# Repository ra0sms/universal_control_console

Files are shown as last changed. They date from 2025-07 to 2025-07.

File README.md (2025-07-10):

## Universal Control Console (UCC)

The device can control any type of antenna switches. It has 8 independent programmable outputs and also can control [my version of receiving antenna K9AY](https://github.com/ra0sms/K9AY_with_wifi).

More information (in Russian, but Translate button still works) - https://ra0sms.com/ucc/

### [Schematic](KiCad/wired_console_k9ay/wired_console_k9ay.pdf)

### Outputs description

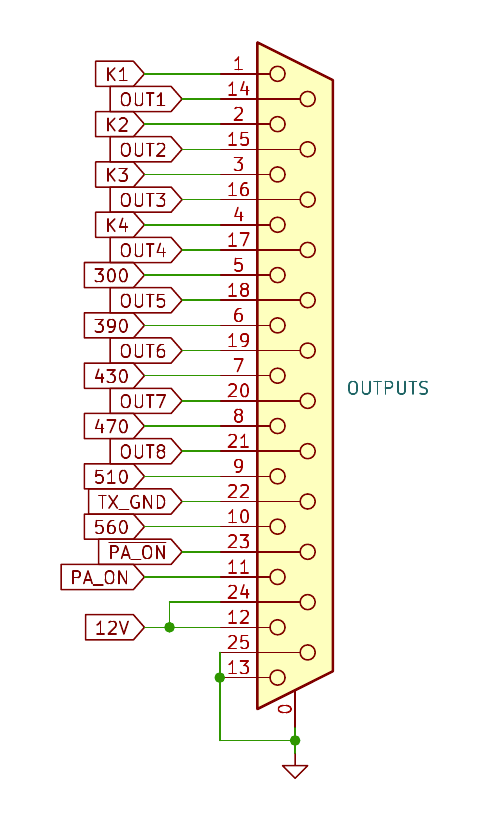
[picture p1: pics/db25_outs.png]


| DB25 pins | Description |
| --- | --- |
| 1 | **K1** - open collector out for K9AY direction control |
| 2 | **K2** - open collector out for K9AY direction control |
| 3 | **K3** - open collector out for K9AY direction control |
| 4 | **K4** - open collector out for K9AY direction control |
| 5 | **300** - open collector out for K9AY load control |
| 6 | **390** - open collector out for K9AY load control |
| 7 | **430** - open collector out for K9AY load control |
| 8 | **470** - open collector out for K9AY load control |
| 9 | **510** - open collector out for K9AY load control |
| 10 | **560** - open collector out for K9AY load control |
| 11 | **PA_ON** - open collector out for K9AY preamplifier control |
| 12 | **12V** - output voltage (goes directly from power supply connector with the diode protection) |
| 13 | **GND** - Ground |
| 14 | **OUT1** - First programmable output (when activated, has 12V out with fuse protection) |
| 15 | **OUT2** - Second programmable output (when activated, has 12V out with fuse protection) |
| 16 | **OUT3** - Third programmable output (when activated, has 12V out with fuse protection) |
| 17 | **OUT4** - Fourth programmable output (when activated, has 12V out with fuse protection) |
| 18 | **OUT5** - Fifth programmable output (when activated, has 12V out with fuse protection) |
| 19 | **OUT6** - Sixth programmable output (when activated, has 12V out with fuse protection) |
| 20 | **OUT7** - Seventh programmable output (when activated, has 12V out with fuse protection) |
| 21 | **OUT8** - Eighth programmable output (when activated, has 12V out with fuse protection) |
| 22 | **TX_GND** - when PTT activated, has connection to ground |
| 23 | **$\overline{\text{PAON}}$** - when Preamp button pressed, has 12V out without any protection |
| 24 | **12V** - output voltage (goes directly from power supply connector with the diode protection) |
| 25 | **GND** - Ground |

### Some photos

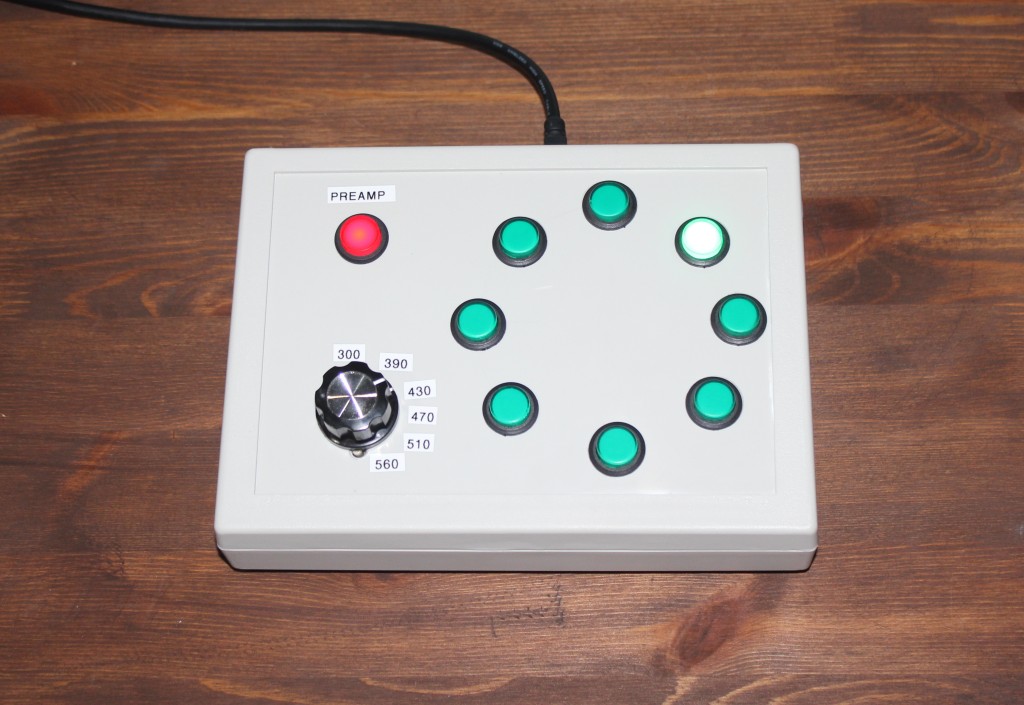
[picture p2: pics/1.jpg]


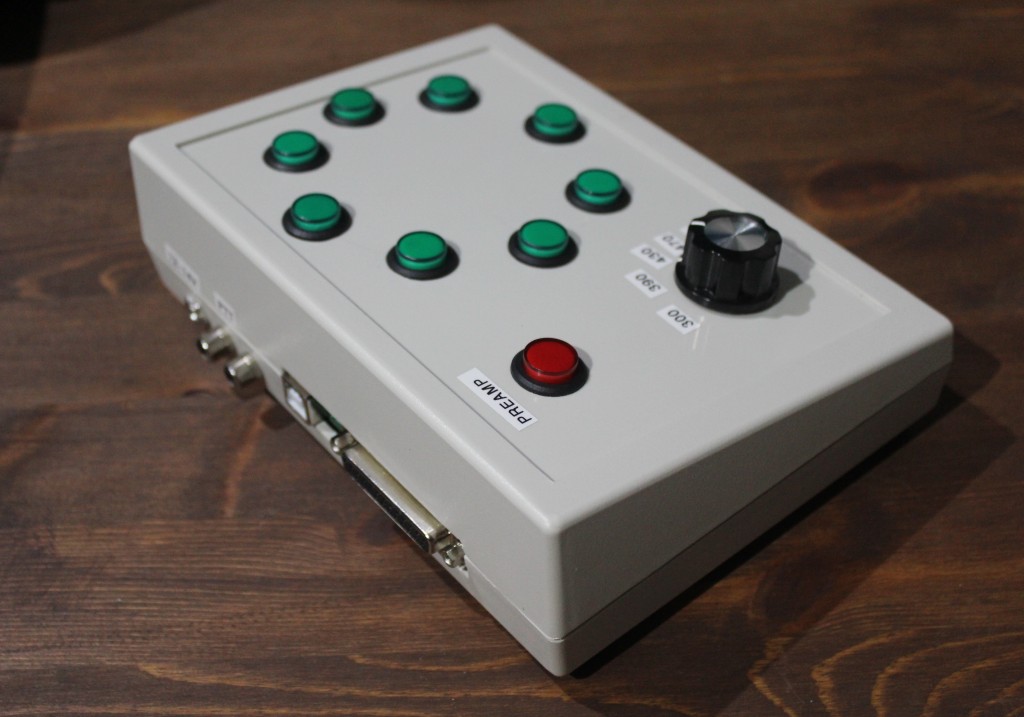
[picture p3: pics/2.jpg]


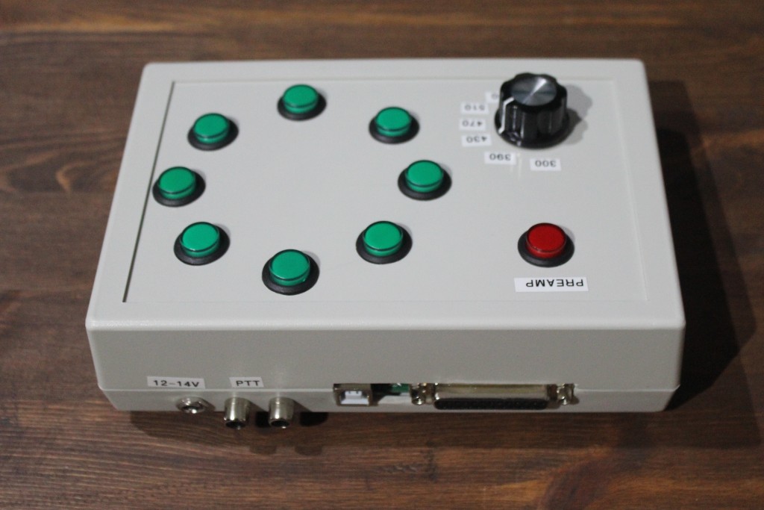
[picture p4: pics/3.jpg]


### GUI software for setting up outputs

You can choose outputs which will be activated when you push the buttons. Just connect USB to PC, choose com port and click Connect button.

[EXE-file (Windows OS)](gui/gui.zip)

[Python Script (Linux OS)](gui/gui.py)

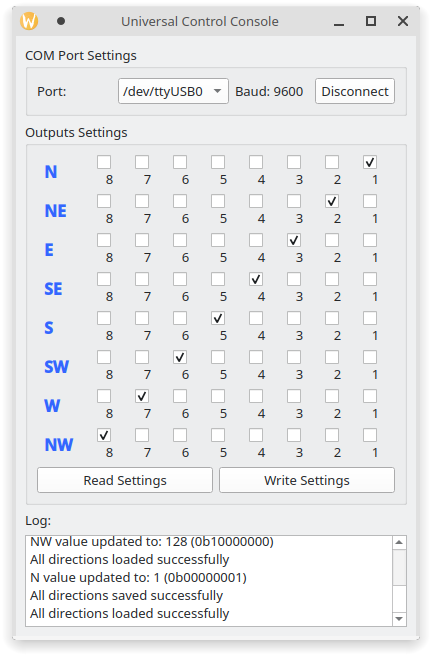
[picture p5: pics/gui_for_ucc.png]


### Antenna rotators emulator

UCC also can work with hamradio software, which use Yaesu rotator protocol. UCC can emulate a rotation at a given angle. You can use it with any supported software. For example [PST Rotator AZ](https://www.pstrotator.com/) and [DXLog](https://dxlog.net/).

### [Video with example or working](https://youtu.be/TXcX0s2ozSk)

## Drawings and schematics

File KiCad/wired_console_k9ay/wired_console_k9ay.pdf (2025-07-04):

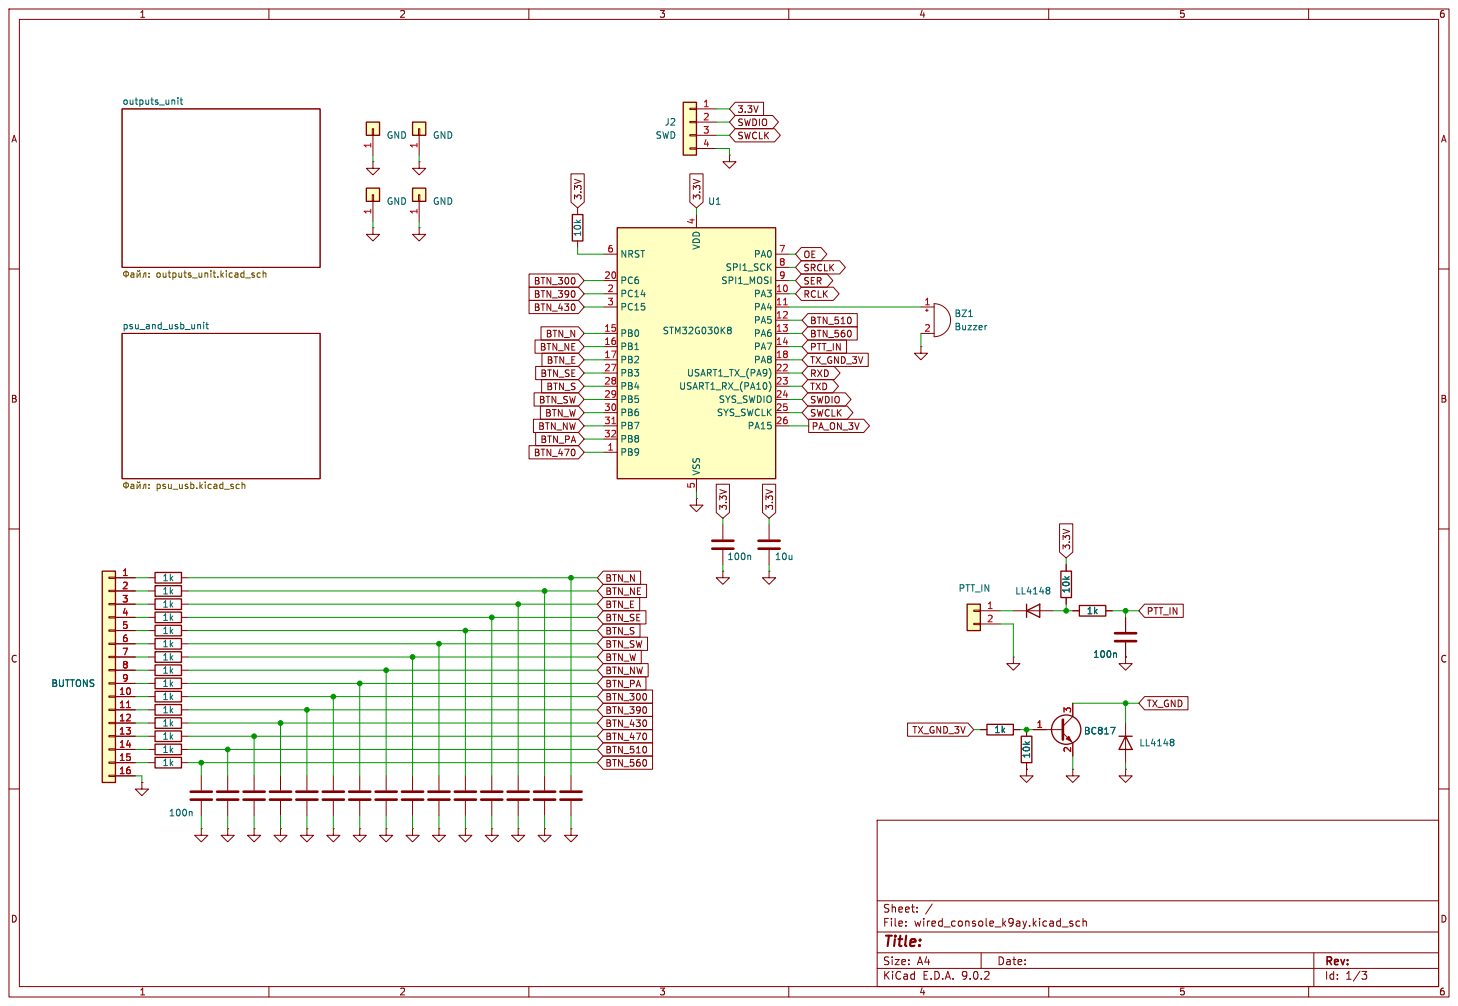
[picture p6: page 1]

Id: 1/3 Title: File: wired_console_k9ay.kicad_sch Sheet: /

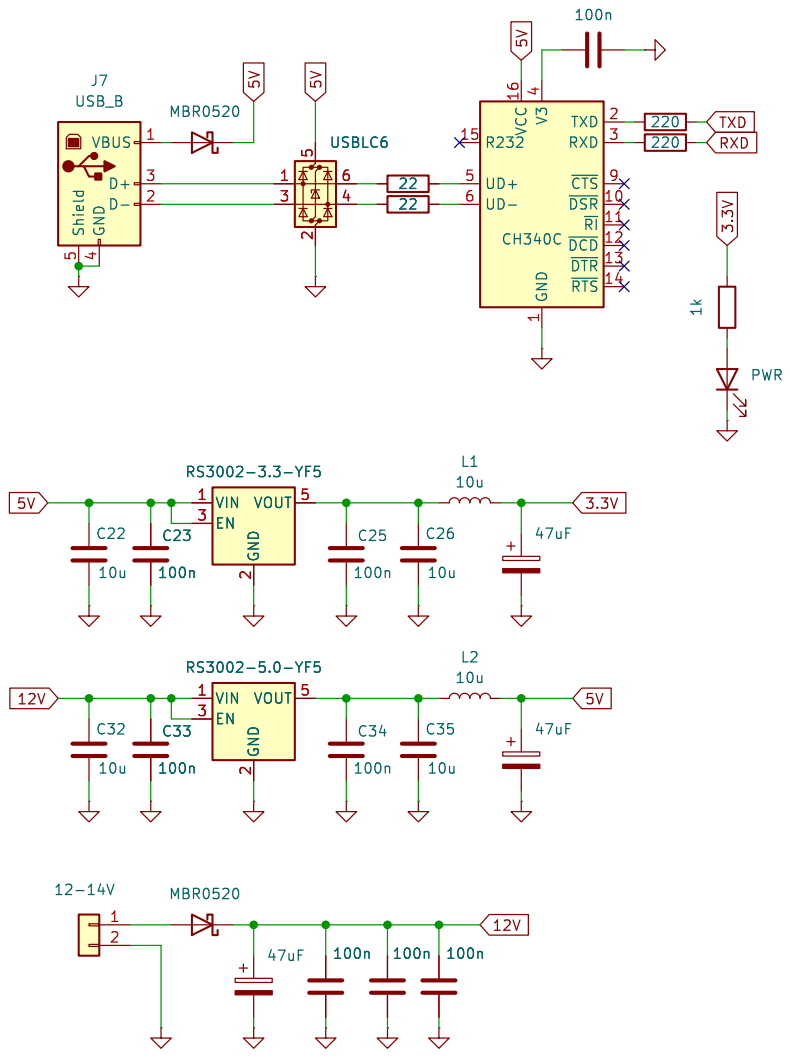
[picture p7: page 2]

Id: 2/3 Title: File: psu_usb.kicad_sch Sheet: /psu_and_usb_unit/ 12

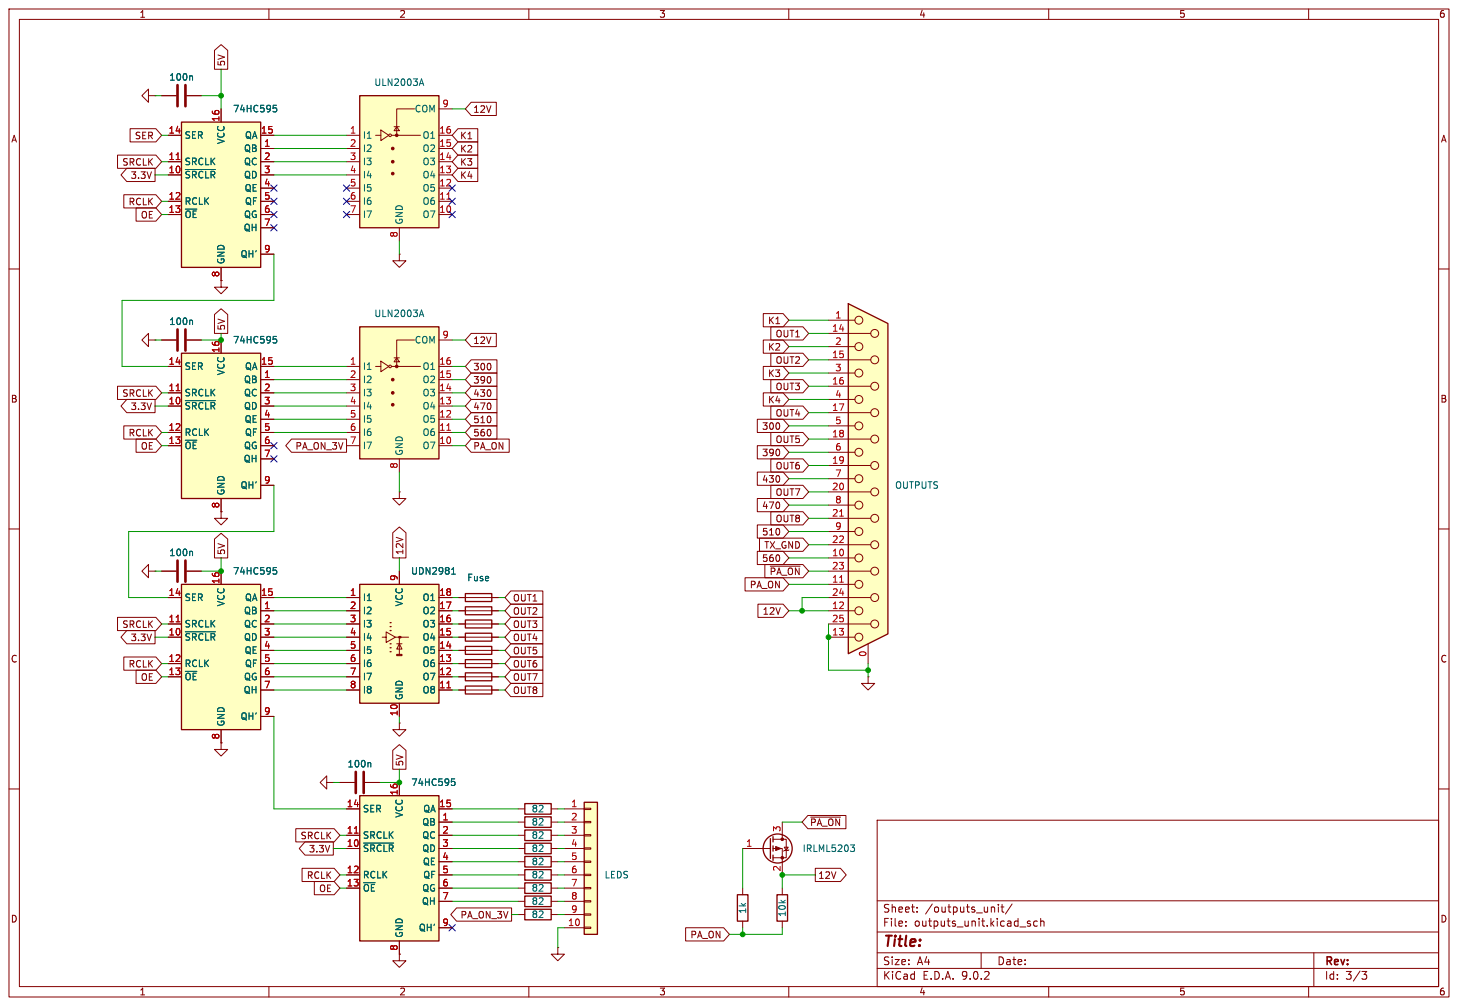
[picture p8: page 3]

Id: 3/3 Title: File: outputs_unit.kicad_sch Sheet: /outputs_unit/

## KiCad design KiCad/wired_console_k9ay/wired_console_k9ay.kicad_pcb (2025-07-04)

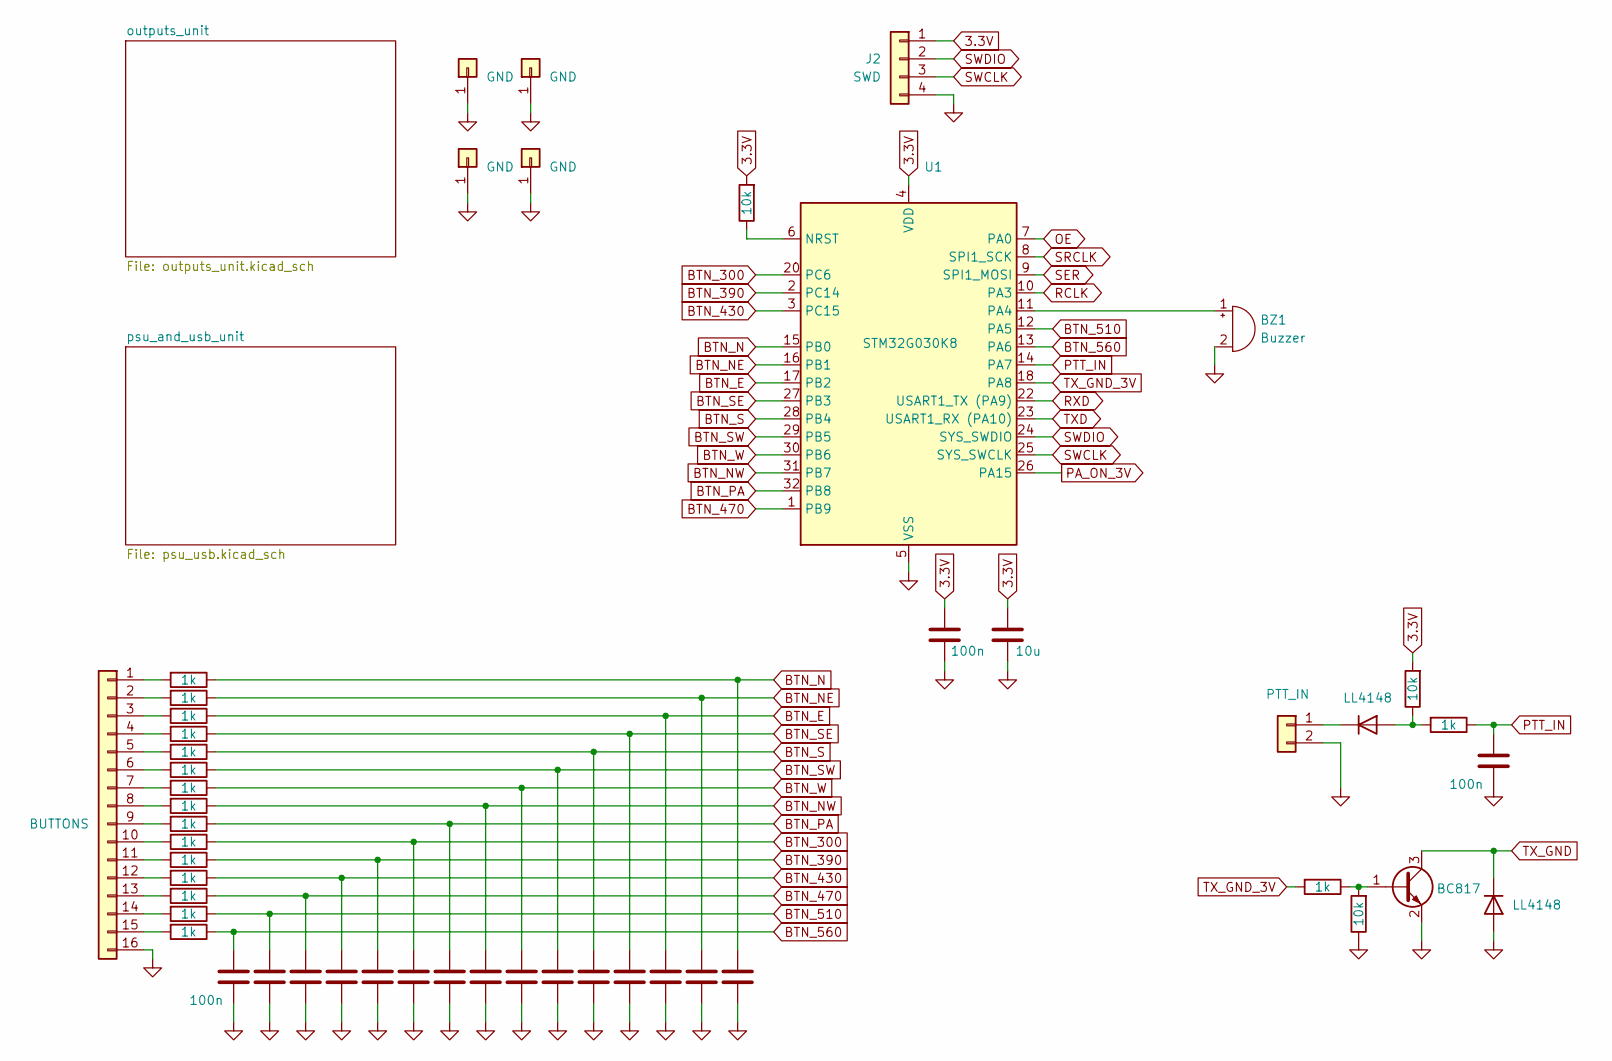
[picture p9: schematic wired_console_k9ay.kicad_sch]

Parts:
BZ1: Buzzer; Buzzer_12x9.5RM7.6
C1, C2, C3, C4, C5, C6, C7, C8, C9, C10, C11, C12, C13, C14, C15, C16, C37: 100n; C_1206_3216Metric_Pad1.33x1.80mm_HandSolder
C17: 10u; C_1206_3216Metric_Pad1.33x1.80mm_HandSolder
D3, D5: LL4148; D_MiniMELF
J1: BUTTONS; PinHeader_1x16_P2.54mm_Vertical
J2: SWD; PinSocket_1x04_P2.54mm_Vertical
J3: PTT_IN; PinHeader_1x02_P2.54mm_Vertical
J8, J9, J10, J11: GND; SolderWire-6sqmm_1x01_D3.5mm_OD7mm
Q2: BC817; SOT-23
R1, R2, R3, R4, R5, R6, R7, R8, R9, R10, R11, R12, R13, R14, R15, R34, R36: 1k; R_1206_3216Metric
R16, R33, R35: 10k; R_1206_3216Metric
U1: STM32G030K8; LQFP-32_7x7mm_P0.8mm

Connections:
3.3V: C16.1, C17.1, J2.1, R16.2, R33.2, U1.4 (VDD); also elsewhere on the board
BTN_300: C6.1, R10.1, U1.20 (PC6)
BTN_390: C5.1, R11.1, U1.2 (PC14)
BTN_430: C4.1, R12.1, U1.3 (PC15)
BTN_470: C3.1, R13.1, U1.1 (PB9)
BTN_510: C2.1, R14.1, U1.12 (PA5)
BTN_560: C1.1, R15.1, U1.13 (PA6)
BTN_E: C13.1, R3.1, U1.17 (PB2)
BTN_N: C15.1, R1.1, U1.15 (PB0)
BTN_NE: C14.1, R2.1, U1.16 (PB1)
BTN_NW: C8.1, R8.1, U1.31 (PB7)
BTN_PA: C7.1, R9.1, U1.32 (PB8)
BTN_S: C11.1, R5.1, U1.28 (PB4)
BTN_SE: C12.1, R4.1, U1.27 (PB3)
BTN_SW: C10.1, R6.1, U1.29 (PB5)
BTN_W: C9.1, R7.1, U1.30 (PB6)
GND: BZ1.2 (-), C1.2, C2.2, C3.2, C4.2, C5.2, C6.2, C7.2, C8.2, C9.2, C10.2, C11.2, C12.2, C13.2, C14.2, C15.2, C16.2, C17.2, C37.2, D5.2 (A), J1.16, J2.4, J3.2, J8.1, J9.1, J10.1, J11.1, Q2.2 (E), R35.1, U1.5 (VSS); also elsewhere on the board
unnamed: BZ1.1 (+), U1.11 (PA4)
unnamed: D3.2 (A), R33.1, R34.2
unnamed: D3.1 (K), J3.1
unnamed: J1.1, R1.2
unnamed: J1.2, R2.2
unnamed: J1.3, R3.2
unnamed: J1.4, R4.2
unnamed: J1.5, R5.2
unnamed: J1.6, R6.2
unnamed: J1.7, R7.2
unnamed: J1.8, R8.2
unnamed: J1.9, R9.2
unnamed: J1.10, R10.2
unnamed: J1.11, R11.2
unnamed: J1.12, R12.2
unnamed: J1.13, R13.2
unnamed: J1.14, R14.2
unnamed: J1.15, R15.2
unnamed: Q2.1 (B), R35.2, R36.1
unnamed: R16.1, U1.6 (NRST)
OE: U1.7 (PA0); also elsewhere on the board
PA_ON_3V: U1.26 (PA15); also elsewhere on the board
PTT_IN: C37.1, R34.1, U1.14 (PA7)
RCLK: U1.10 (PA3); also elsewhere on the board
RXD: U1.22 (USART1_TX (PA9)); also elsewhere on the board
SER: U1.9 (SPI1_MOSI); also elsewhere on the board
SRCLK: U1.8 (SPI1_SCK); also elsewhere on the board
SWCLK: J2.3, U1.25 (SYS_SWCLK)
SWDIO: J2.2, U1.24 (SYS_SWDIO)
TXD: U1.23 (USART1_RX (PA10)); also elsewhere on the board
TX_GND: D5.1 (K), Q2.3 (C); also elsewhere on the board
TX_GND_3V: R36.2, U1.18 (PA8)

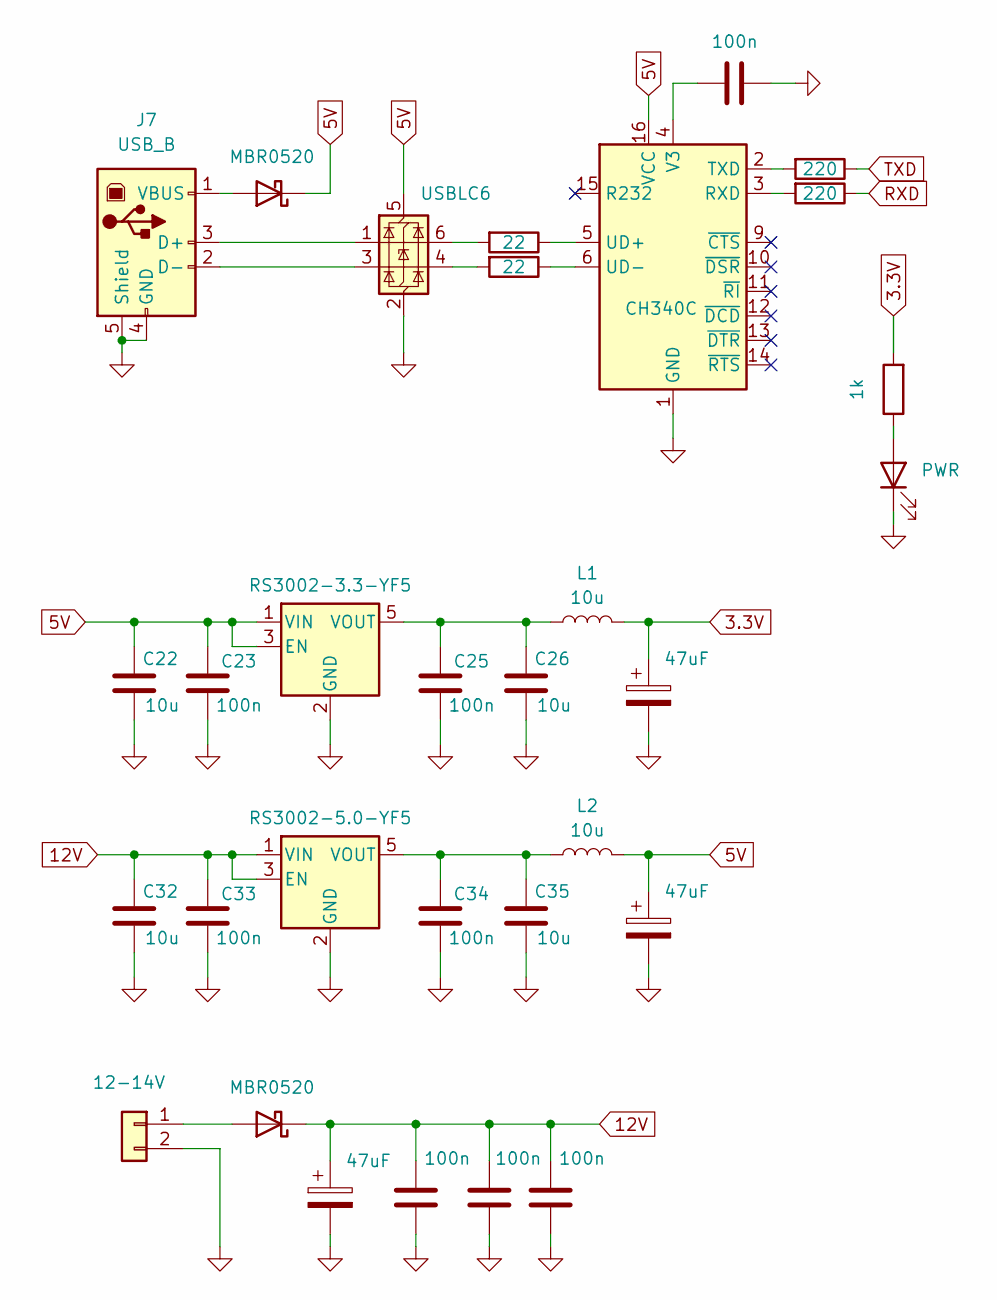
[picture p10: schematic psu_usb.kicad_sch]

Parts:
C18, C27, C36: 47uF; CP_Radial_D5.0mm_P2.50mm
C19, C20, C21, C24: 100n; C_1206_3216Metric
C22, C26, C32, C35: 10u; C_1206_3216Metric_Pad1.33x1.80mm_HandSolder
C23, C25, C33, C34: 100n; C_1206_3216Metric_Pad1.33x1.80mm_HandSolder
D1, D2: MBR0520; D_SOD-123
D4: PWR; LED_1206_3216Metric
J4: 12-14V; PinHeader_1x02_P2.54mm_Vertical
J7: USB_B; USB_B_Lumberg_2411_02_Horizontal
L1, L2: 10u; L_1206_3216Metric
R17, R18: 22; R_1206_3216Metric
R19, R20: 220; R_1206_3216Metric
R21: 1k; R_1206_3216Metric
U2: USBLC6; SOT-23-6
U3: CH340C; SOIC-16_3.9x9.9mm_P1.27mm
U4: RS3002-3.3-YF5; SOT-23-5
U12: RS3002-5.0-YF5; SOT-23-5

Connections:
3.3V: C27.1, L1.2, R21.2; also elsewhere on the board
5V: C22.1, C23.1, C36.1, D2.1 (K), L2.2, U2.5 (VBUS), U3.16 (VCC), U4.1 (VIN), U4.3 (EN); also elsewhere on the board
12V: C18.1, C19.1, C20.1, C21.1, C32.1, C33.1, D1.1 (K), U12.1 (VIN), U12.3 (EN); also elsewhere on the board
GND: C18.2, C19.2, C20.2, C21.2, C22.2, C23.2, C24.2, C25.2, C26.2, C27.2, C32.2, C33.2, C34.2, C35.2, C36.2, D4.1 (K), J4.2, J7.4 (GND), J7.5 (Shield), U2.2 (GND), U3.1 (GND), U4.2 (GND), U12.2 (GND); also elsewhere on the board
unnamed: D1.2 (A), J4.1
unnamed: D2.2 (A), J7.1 (VBUS)
unnamed: D4.2 (A), R21.1
unnamed: J7.3 (D+), U2.1 (I/O1)
unnamed: J7.2 (D-), U2.3 (I/O2)
unnamed: R17.2, U2.6 (I/O1)
unnamed: R18.2, U2.4 (I/O2)
unnamed: R20.2, U3.3 (RXD)
unnamed: R19.2, U3.2 (TXD)
unnamed: R17.1, U3.5 (UD+)
unnamed: R18.1, U3.6 (UD-)
unnamed: C24.1, U3.4 (V3)
unnamed: C25.1, C26.1, L1.1, U4.5 (VOUT)
unnamed: C34.1, C35.1, L2.1, U12.5 (VOUT)
RXD: R20.1; also elsewhere on the board
TXD: R19.1; also elsewhere on the board

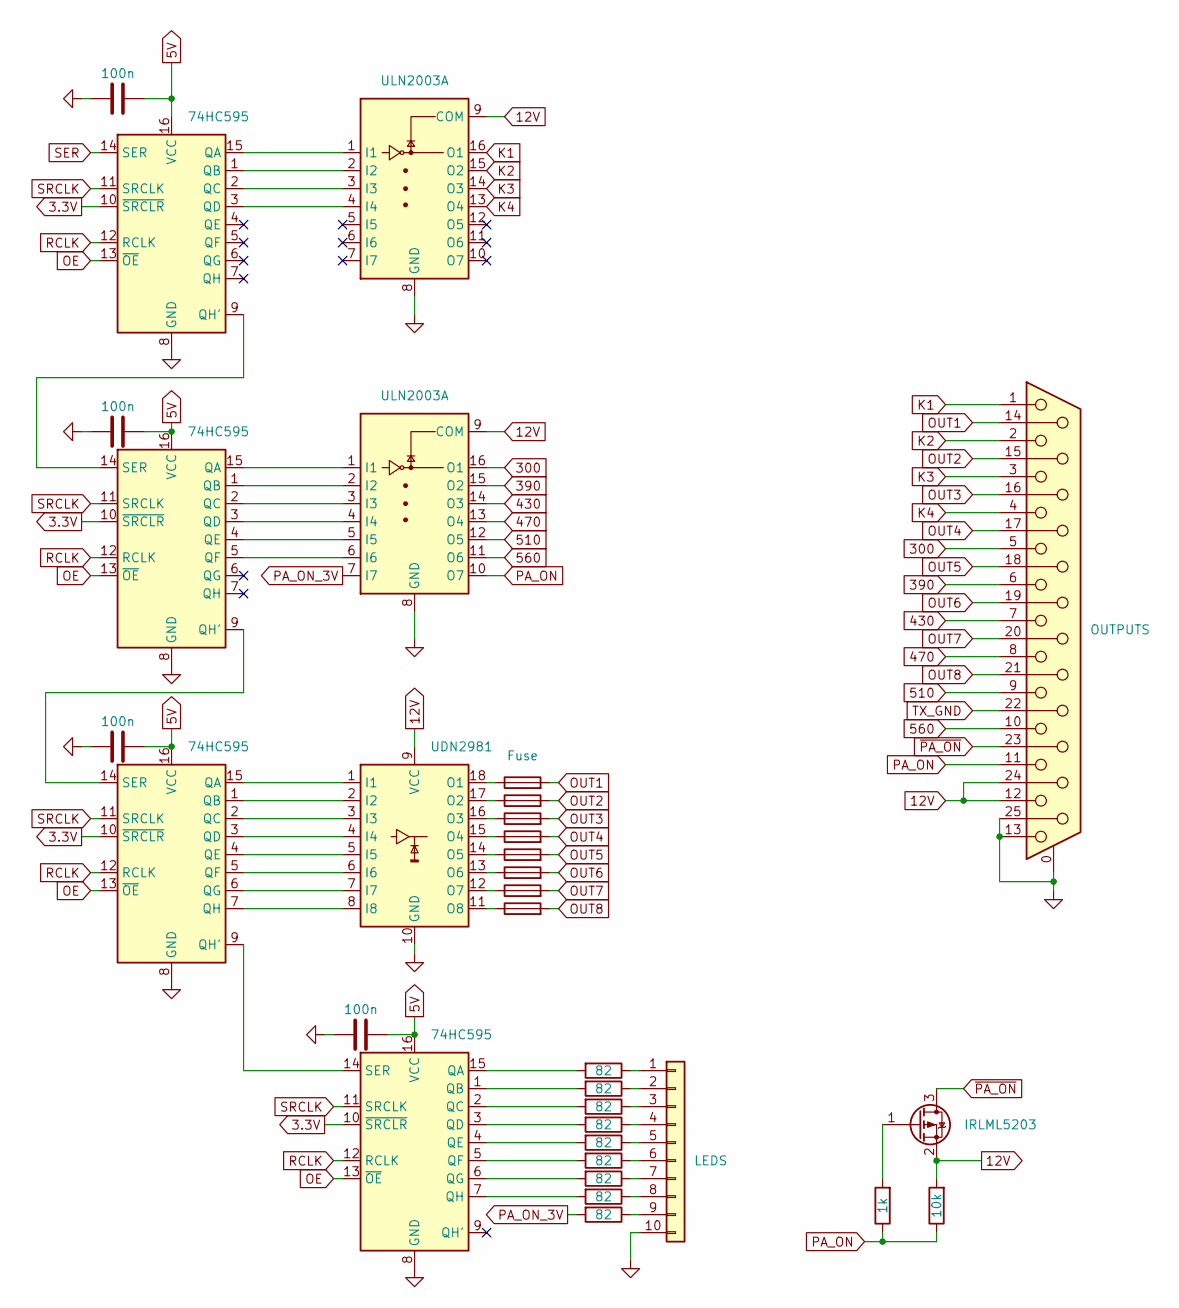
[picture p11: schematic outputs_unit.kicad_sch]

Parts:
C28, C29, C30, C31: 100n; C_1206_3216Metric
F1, F2, F3, F4, F5, F6, F7, F8: Fuse; R_1206_3216Metric
J5: LEDS; PinSocket_1x10_P2.54mm_Vertical
J6: OUTPUTS; DSUB-25_Socket_Horizontal_P2.77x2.84mm_EdgePinOffset4.94mm_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
Q1: IRLML5203; SOT-23
R22, R23, R24, R25, R26, R27, R28, R29, R30: 82; R_1206_3216Metric
R31: 1k; R_1206_3216Metric
R32: 10k; R_1206_3216Metric
U5, U6, U7, U11: 74HC595; SOIC-16_3.9x9.9mm_P1.27mm
U8, U9: ULN2003A; SOIC-16_3.9x9.9mm_P1.27mm
U10: UDN2981; DIP-18_W7.62mm_LongPads

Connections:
3.3V: U5.10 (~SRCLR), U6.10 (~SRCLR), U7.10 (~SRCLR), U11.10 (~SRCLR); also elsewhere on the board
5V: C28.2, C29.2, C30.2, C31.2, U5.16 (VCC), U6.16 (VCC), U7.16 (VCC), U11.16 (VCC); also elsewhere on the board
12V: J6.12, J6.24, Q1.2 (S), R32.2, U8.9 (COM), U9.9 (COM), U10.9 (VCC); also elsewhere on the board
300: J6.5, U9.16 (O1)
390: J6.6, U9.15 (O2)
430: J6.7, U9.14 (O3)
470: J6.8, U9.13 (O4)
510: J6.9, U9.12 (O5)
560: J6.10, U9.11 (O6)
GND: C28.1, C29.1, C30.1, C31.1, J5.10, J6.0 (PAD), J6.13, J6.25, U5.8 (GND), U6.8 (GND), U7.8 (GND), U8.8 (GND), U9.8 (GND), U10.10 (GND), U11.8 (GND); also elsewhere on the board
K1: J6.1, U8.16 (O1)
K2: J6.2, U8.15 (O2)
K3: J6.3, U8.14 (O3)
K4: J6.4, U8.13 (O4)
unnamed: J5.1, R22.1
unnamed: J5.2, R23.1
unnamed: J5.3, R24.1
unnamed: J5.4, R25.1
unnamed: J5.5, R26.1
unnamed: J5.6, R27.1
unnamed: J5.7, R28.1
unnamed: J5.8, R29.1
unnamed: J5.9, R30.1
unnamed: Q1.1 (G), R31.2
unnamed: U5.15 (QA), U8.1 (I1)
unnamed: U5.1 (QB), U8.2 (I2)
unnamed: U5.2 (QC), U8.3 (I3)
unnamed: U5.3 (QD), U8.4 (I4)
unnamed: U5.9 (QH'), U6.14 (SER)
unnamed: U6.15 (QA), U9.1 (I1)
unnamed: U6.1 (QB), U9.2 (I2)
unnamed: U6.2 (QC), U9.3 (I3)
unnamed: U6.3 (QD), U9.4 (I4)
unnamed: U6.4 (QE), U9.5 (I5)
unnamed: U6.5 (QF), U9.6 (I6)
unnamed: U6.9 (QH'), U7.14 (SER)
unnamed: U7.15 (QA), U10.1 (I1)
unnamed: U7.1 (QB), U10.2 (I2)
unnamed: U7.2 (QC), U10.3 (I3)
unnamed: U7.3 (QD), U10.4 (I4)
unnamed: U7.4 (QE), U10.5 (I5)
unnamed: U7.5 (QF), U10.6 (I6)
unnamed: U7.6 (QG), U10.7 (I7)
unnamed: U7.7 (QH), U10.8 (I8)
unnamed: F1.1, U10.18 (O1)
unnamed: F2.1, U10.17 (O2)
unnamed: F3.1, U10.16 (O3)
unnamed: F4.1, U10.15 (O4)
unnamed: F5.1, U10.14 (O5)
unnamed: F6.1, U10.13 (O6)
unnamed: F7.1, U10.12 (O7)
unnamed: F8.1, U10.11 (O8)
unnamed: R22.2, U11.15 (QA)
unnamed: R23.2, U11.1 (QB)
unnamed: R24.2, U11.2 (QC)
unnamed: R25.2, U11.3 (QD)
unnamed: R26.2, U11.4 (QE)
unnamed: R27.2, U11.5 (QF)
unnamed: R28.2, U11.6 (QG)
unnamed: R29.2, U11.7 (QH)
unnamed: U7.9 (QH'), U11.14 (SER)
OE: U5.13 (~OE), U6.13 (~OE), U7.13 (~OE), U11.13 (~OE); also elsewhere on the board
OUT1: F1.2, J6.14
OUT2: F2.2, J6.15
OUT3: F3.2, J6.16
OUT4: F4.2, J6.17
OUT5: F5.2, J6.18
OUT6: F6.2, J6.19
OUT7: F7.2, J6.20
OUT8: F8.2, J6.21
PA_ON: J6.11, R31.1, R32.1, U9.10 (O7)
PA_ON_3V: R30.2, U9.7 (I7); also elsewhere on the board
RCLK: U5.12 (RCLK), U6.12 (RCLK), U7.12 (RCLK), U11.12 (RCLK); also elsewhere on the board
SER: U5.14 (SER); also elsewhere on the board
SRCLK: U5.11 (SRCLK), U6.11 (SRCLK), U7.11 (SRCLK), U11.11 (SRCLK); also elsewhere on the board
TX_GND: J6.22; also elsewhere on the board
~PA_ON: J6.23, Q1.3 (D)

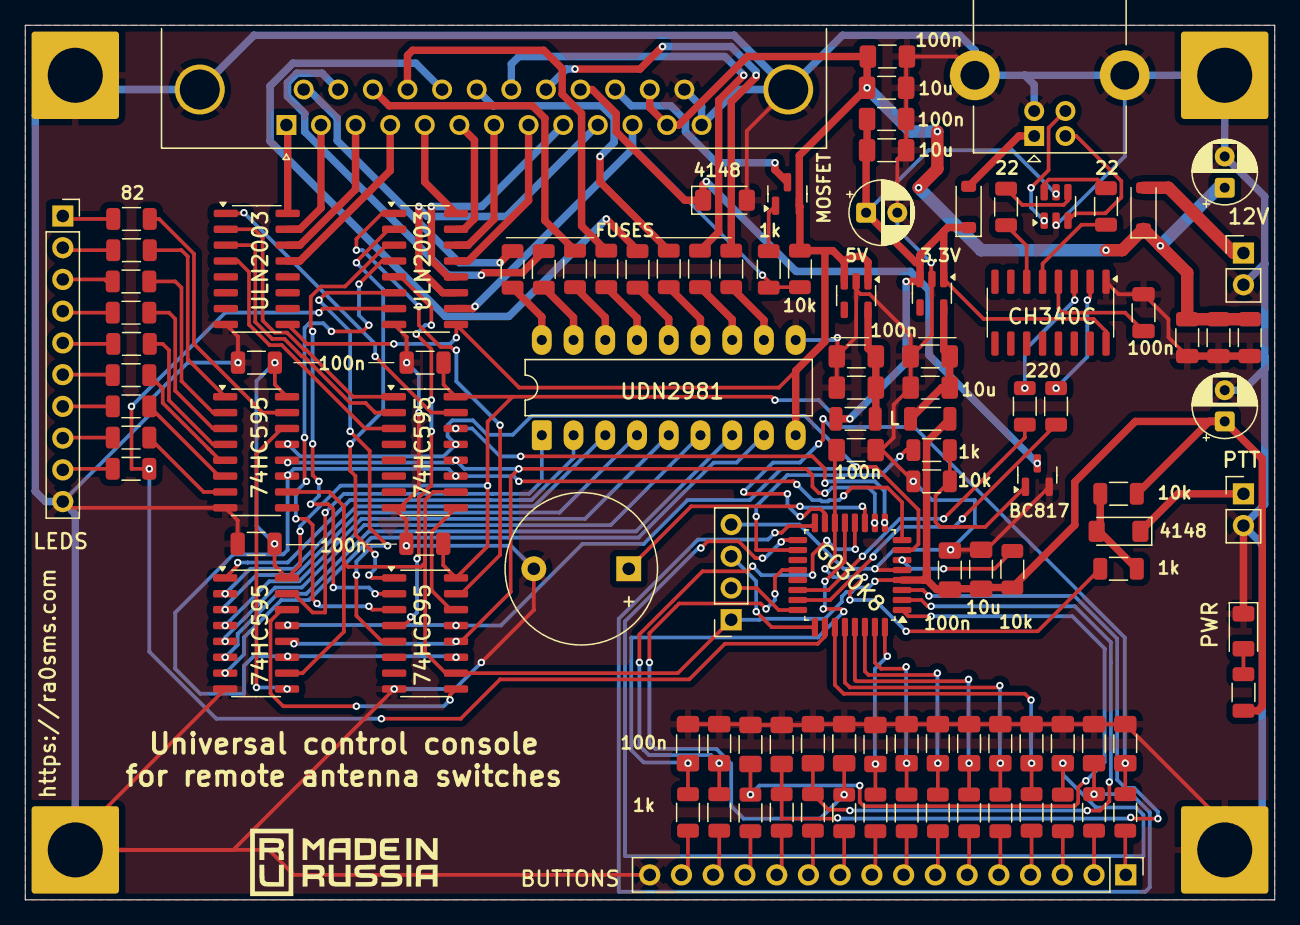
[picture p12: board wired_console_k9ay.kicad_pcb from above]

Board: 2 copper layers, 100.0 x 70.0 mm, 114 parts (0 on the bottom side), 132 nets.

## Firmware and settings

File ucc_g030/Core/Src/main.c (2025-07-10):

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
/* Includes ------------------------------------------------------------------*/
#include "main.h"
SPI_HandleTypeDef hspi1;

void SystemClock_Config(void);
static void MX_GPIO_Init(void);
static void MX_SPI1_Init(void);
static void MX_USART1_UART_Init(void);
static void MX_TIM17_Init(void);
/* USER CODE BEGIN PFP */
void USART1_Send_String (char* str);
char* ConvertGradusToChar (uint32_t degree);
void Check_Usart_Data();
void USART1_Send (char chr);
uint32_t ConvertCharToGradus(char * buffer);
void Send_Azimuth_to_USART(int az);
uint8_t Button_Pressed(uint8_t btn_id);
void Init_Buttons();
void Buttons_Poll(void);
void Set_N(void);
void Set_NE(void);
void Set_E(void);
void Set_SE(void);
void Set_S(void);
void Set_SW(void);
void Set_W(void);
void Set_NW(void);
void Set_300(void);
void Set_390(void);
void Set_430(void);
void Set_470(void);
void Set_510(void);
void Set_560(void);
void Set_PA(void);
void Check_PTT(void);



/* USER CODE END PFP */

/* USER CODE BEGIN 0 */
uint8_t relay_outs[1] = {0};
uint8_t load_outs[1] = {0};
uint8_t udn_outs[1] = {0};
uint8_t led_outs[1] = {0};
uint8_t flag_stop = 0;
uint8_t flag_status = 0;
uint8_t flag_move = 0;
uint8_t flag_set_settings = 0;
uint8_t flag_get_settings = 0;
int current_azimuth = 0;
char rx_buffer[32];
uint8_t current_outs_settings[8];
static uint8_t pa_previous_state = 0;
static uint8_t ptt_active = 0;

uint8_t button_settings[8] = {1, 2, 4, 8, 16, 32, 64, 128};

#define BUTTON_COUNT 15
#define DEBOUNCE_MS 25
#define POLL_INTERVAL_MS 5

typedef struct {
  GPIO_TypeDef* port;
  uint32_t pin;
  uint8_t state;
  uint8_t prev_state;
  uint32_t last_change;
} Button;

static Button buttons[BUTTON_COUNT];
static uint32_t system_tick = 0;

// Объявляем тип для функций-обработчиков
typedef void (*ButtonHandler)(void);

// Массив обработчиков для каждой кнопки
static const ButtonHandler button_handlers[] = {
  Set_N,   // 0
  Set_NE,  // 1
  Set_E,   // 2
  Set_SE,  // 3
  Set_S,   // 4
  Set_SW,  // 5
  Set_W,   // 6
  Set_NW,  // 7
  Set_300, // 8
  Set_390, // 9
  Set_430, // 10
  Set_470, // 11
  Set_510, // 12
  Set_560, // 13
  Set_PA   // 14
};


#define SETTINGS_FLASH_ADDR  0x0800F800  // Последняя страница 2KB Flash
#define SETTINGS_MAGIC_NUM   0xAA55BB66  // Маркер валидности данных

typedef struct {
  uint32_t magic;      // Маркер валидности
  uint8_t btn_values[8]; // Значения кнопок (0-255)
  uint32_t crc32;      // Контрольная сумма
} ButtonSettings;

uint32_t Calculate_CRC32(const uint8_t* data, size_t length) {
  uint32_t crc = 0xFFFFFFFF;
  for (size_t i = 0; i < length; i++) {
    crc ^= data[i];
    for (int j = 0; j < 8; j++) {
      crc = (crc >> 1) ^ (0xEDB88320 & -(crc & 1));
    }
  }
  return ~crc;
}

HAL_StatusTypeDef Save_Button_Settings(const uint8_t* values) {
  ButtonSettings settings;

  // Подготовка структуры
  settings.magic = SETTINGS_MAGIC_NUM;
  memcpy(settings.btn_values, values, 8);
  settings.crc32 = Calculate_CRC32((uint8_t*)&settings, sizeof(ButtonSettings)-4);

  // Стирание страницы
  HAL_FLASH_Unlock();
  FLASH_EraseInitTypeDef erase = {
    .TypeErase = FLASH_TYPEERASE_PAGES,
    .Page = (SETTINGS_FLASH_ADDR - FLASH_BASE) / FLASH_PAGE_SIZE,
    .NbPages = 1
};
  uint32_t page_error;
  HAL_FLASHEx_Erase(&erase, &page_error);

  // Запись данных
  uint64_t* data = (uint64_t*)&settings;
  for (int i = 0; i < sizeof(ButtonSettings)/8; i++) {
    HAL_FLASH_Program(FLASH_TYPEPROGRAM_DOUBLEWORD,
                    SETTINGS_FLASH_ADDR + i*8,
                    data[i]);
  }
  HAL_FLASH_Lock();

  return HAL_OK;
}


HAL_StatusTypeDef Load_Button_Settings(uint8_t* values) {
  ButtonSettings* settings = (ButtonSettings*)SETTINGS_FLASH_ADDR;

  // Проверка маркера и CRC
  if (settings->magic != SETTINGS_MAGIC_NUM ||
      settings->crc32 != Calculate_CRC32((uint8_t*)settings, sizeof(ButtonSettings)-4)) {
    return HAL_ERROR; // Данные невалидны
      }

  memcpy(values, settings->btn_values, 8);
  return HAL_OK;
}

void Beep(uint32_t duration_ms) {
  LL_GPIO_SetOutputPin(BUZZER_GPIO_Port, BUZZER_Pin);
  LL_mDelay(duration_ms);
  LL_GPIO_ResetOutputPin(BUZZER_GPIO_Port, BUZZER_Pin);
}

void Buttons_Poll(void) {
  system_tick += POLL_INTERVAL_MS;
  if (system_tick >= UINT32_MAX - POLL_INTERVAL_MS) system_tick = 0;
}


void Init_Buttons(void) {
  // Конфигурация всех кнопок
  const struct {
    GPIO_TypeDef* port;
    uint32_t pin;
  } button_configs[] = {
    [0] = {BTN_N_GPIO_Port, BTN_N_Pin},
    [1] = {BTN_NE_GPIO_Port, BTN_NE_Pin},
    [2] = {BTN_E_GPIO_Port, BTN_E_Pin},
    [3] = {BTN_SE_GPIO_Port, BTN_SE_Pin},
    [4] = {BTN_S_GPIO_Port, BTN_S_Pin},
    [5] = {BTN_SW_GPIO_Port, BTN_SW_Pin},
    [6] = {BTN_W_GPIO_Port, BTN_W_Pin},
    [7] = {BTN_NW_GPIO_Port, BTN_NW_Pin},
    [8] = {BTN_300_GPIO_Port, BTN_300_Pin},
    [9] = {BTN_390_GPIO_Port, BTN_390_Pin},
    [10] = {BTN_430_GPIO_Port, BTN_430_Pin},
    [11] = {BTN_470_GPIO_Port, BTN_470_Pin},
    [12] = {BTN_510_GPIO_Port, BTN_510_Pin},
    [13] = {BTN_560_GPIO_Port, BTN_560_Pin},
    [14] = {BTN_PA_GPIO_Port, BTN_PA_Pin}
  };
  const uint8_t button_count = sizeof(button_configs)/sizeof(button_configs[0]);
  for (uint8_t i = 0; i < button_count; i++) {
    buttons[i] = (Button){
      .port = button_configs[i].port,
      .pin = button_configs[i].pin,
      .state = 0,          // Исходное состояние - не нажата
      .prev_state = 0,     // Предыдущее состояние - не нажата
      .last_change = 0     // Время последнего изменения
    };
  }
}


// Проверка нажатия кнопки (возвращает 1 при нажатии)
uint8_t Button_Pressed(uint8_t btn_id) {
  if (btn_id >= BUTTON_COUNT) return 0;

  Button* btn = &buttons[btn_id];
  uint8_t current = LL_GPIO_IsInputPinSet(btn->port, btn->pin) ? 0 : 1;

  // Если состояние изменилось
  if (current != btn->prev_state) {
    btn->last_change = system_tick;
    btn->prev_state = current;
  }
  // Если состояние стабильно дольше времени дребезга
  else if ((system_tick - btn->last_change) >= DEBOUNCE_MS) {
    if (current && !btn->state) {
      btn->state = current;
      return 1;
    }
    btn->state = current;
  }

  return 0;
}


uint32_t ConvertCharToGradus(char* buffer) {
  uint32_t result = (buffer[1] - '0') * 100 +
                   (buffer[2] - '0') * 10 +
                   (buffer[3] - '0');
  memset(buffer, 0, 6);
  return result;
}

char* ConvertGradusToChar(uint32_t degree)
{
  static char result[10];
  degree = degree % 1000;
  snprintf(result, sizeof(result), "+0%03d\r\n", degree);
  return result;
}

void Send_Azimuth_to_USART(int az) {
  if (((az>=0) && (az<= 22)) ||(az > 337)&&(az<=360))
    current_azimuth = 0;
  if ((az>=23) && (az<= 67))
    current_azimuth = 45;
  if ((az>=68) && (az<= 112))
    current_azimuth = 90;
  if ((az>=113) && (az<= 157))
    current_azimuth = 135;
  if ((az>=158) && (az<= 202))
    current_azimuth = 180;
  if ((az>=203) && (az<= 247))
    current_azimuth = 225;
  if ((az>=248) && (az<= 292))
    current_azimuth = 270;
  if ((az>=293) && (az<= 337))
    current_azimuth = 315;
  USART1_Send_String(ConvertGradusToChar(current_azimuth));
}

void Check_Usart_Data()
{
  if (flag_status)
  {
    char debug_msg[64];
    flag_status = 0;
    memset(rx_buffer, 0, sizeof(rx_buffer));
    USART1_Send_String(ConvertGradusToChar(current_azimuth));
  }
  else if (flag_move)
  {
    int azimuth_from_usart = 0;
    flag_move = 0;
    azimuth_from_usart = ConvertCharToGradus(rx_buffer);
    Send_Azimuth_to_USART(azimuth_from_usart);
    switch (current_azimuth){
      case 0: Set_N(); break;
      case 45: Set_NE(); break;
      case 90: Set_E(); break;
      case 135: Set_SE(); break;
      case 180: Set_S(); break;
      case 225: Set_SW(); break;
      case 270: Set_W(); break;
      case 315: Set_NW(); break;
    }
  }
  else if (flag_stop)
  {
    flag_stop = 0;
  }
  else if (flag_set_settings){
    flag_set_settings = 0;
    if (Save_Button_Settings(current_outs_settings) == HAL_OK) {
      USART1_Send_String("OK: Settings saved\n");
    } else {
      USART1_Send_String("ERR: Save failed\n");
    }
    USART1_Send_String("Values:");
    for (int i = 0; i < 8; i++) {
      char buf[10];
      snprintf(buf, sizeof(buf), " %d", current_outs_settings[i]);
      USART1_Send_String(buf);
    }
    USART1_Send_String("\n");
    Beep(50);
  }
  else if (flag_get_settings) {
    flag_get_settings = 0;
    if (Load_Button_Settings(button_settings) != HAL_OK) {
      memset(button_settings, 0, 8);
    }
    USART1_Send_String("Values:");
    for (int i = 0; i < 8; i++) {
      char buf[10];
      snprintf(buf, sizeof(buf), " %d", current_outs_settings[i]);
      USART1_Send_String(buf);
    }
    USART1_Send_String("\n");
  }
}

void Say_Hi(void) {
  LL_GPIO_SetOutputPin(BUZZER_GPIO_Port, BUZZER_Pin);
  LL_mDelay(50);
  LL_GPIO_ResetOutputPin(BUZZER_GPIO_Port, BUZZER_Pin);
  LL_mDelay(50);
  LL_GPIO_SetOutputPin(BUZZER_GPIO_Port, BUZZER_Pin);
  LL_mDelay(50);
  LL_GPIO_ResetOutputPin(BUZZER_GPIO_Port, BUZZER_Pin);
  LL_mDelay(50);
  LL_GPIO_SetOutputPin(BUZZER_GPIO_Port, BUZZER_Pin);
  LL_mDelay(50);
  LL_GPIO_ResetOutputPin(BUZZER_GPIO_Port, BUZZER_Pin);
  LL_mDelay(50);
  LL_GPIO_SetOutputPin(BUZZER_GPIO_Port, BUZZER_Pin);
  LL_mDelay(50);
  LL_GPIO_ResetOutputPin(BUZZER_GPIO_Port, BUZZER_Pin);
  LL_mDelay(150);
  LL_GPIO_SetOutputPin(BUZZER_GPIO_Port, BUZZER_Pin);
  LL_mDelay(50);
  LL_GPIO_ResetOutputPin(BUZZER_GPIO_Port, BUZZER_Pin);
  LL_mDelay(50);
  LL_GPIO_SetOutputPin(BUZZER_GPIO_Port, BUZZER_Pin);
  LL_mDelay(50);
  LL_GPIO_ResetOutputPin(BUZZER_GPIO_Port, BUZZER_Pin);
  LL_mDelay(50);
}

void USART1_Send (char chr){
  while (!(USART1->ISR & USART_ISR_TC));
  USART1->TDR = chr;
}

void USART1_Send_String (char* str){
  uint8_t i = 0;
  while(str[i])
    USART1_Send (str[i++]);
}

void SetCS()
{
  LL_GPIO_SetOutputPin(RCLK_GPIO_Port, RCLK_Pin);
}

void ResetCS()
{
  LL_GPIO_ResetOutputPin(RCLK_GPIO_Port, RCLK_Pin);
}

void StrobCS()
{
  SetCS();
  ResetCS();
  LL_GPIO_ResetOutputPin(OE_GPIO_Port, OE_Pin);
}

void HC595_Send() {
  ResetCS();
  HAL_SPI_Transmit(&hspi1,(uint8_t*)led_outs, 1, 500);
  HAL_SPI_Transmit(&hspi1,(uint8_t*)udn_outs, 1, 500);
  HAL_SPI_Transmit(&hspi1,(uint8_t*)load_outs, 1, 500);
  HAL_SPI_Transmit(&hspi1,(uint8_t*)relay_outs, 1, 500);
  StrobCS();
}


void Check_Buttons() {
  for (uint8_t i = 0; i < sizeof(button_handlers)/sizeof(button_handlers[0]); i++) {
    if (Button_Pressed(i)) {
      button_handlers[i]();
    }
  }
}

void Set_N() {
  current_azimuth = 0;
  Send_Azimuth_to_USART(current_azimuth);
  led_outs[0] = 0b00000001;
  relay_outs[0] = 0b00001000;
  udn_outs[0] = current_outs_settings[0];
  HC595_Send();
}

void Set_NE() {
  current_azimuth = 45;
  Send_Azimuth_to_USART(current_azimuth);
  led_outs[0] = 0b00000010;
  relay_outs[0] = 0b00001001;
  udn_outs[0] = current_outs_settings[1];
  HC595_Send();
}

void Set_E() {
  current_azimuth = 90;
  Send_Azimuth_to_USART(current_azimuth);
  led_outs[0] = 0b00000100;
  relay_outs[0] = 0b00001100;
  udn_outs[0] = current_outs_settings[2];
  HC595_Send();
}

void Set_SE() {
  current_azimuth = 135;
  Send_Azimuth_to_USART(current_azimuth);
  led_outs[0] = 0b00001000;
  relay_outs[0] = 0b00000010;
  udn_outs[0] = current_outs_settings[3];
  HC595_Send();
}

void Set_S() {
  current_azimuth = 180;
  Send_Azimuth_to_USART(current_azimuth);
  led_outs[0] = 0b00010000;
  relay_outs[0] = 0b00000000;
  udn_outs[0] = current_outs_settings[4];
  HC595_Send();
}

void Set_SW() {
  current_azimuth = 225;
  Send_Azimuth_to_USART(current_azimuth);
  led_outs[0] = 0b00100000;
  relay_outs[0] = 0b00000001;
  udn_outs[0] = current_outs_settings[5];
  HC595_Send();
}

void Set_W() {
  current_azimuth = 270;
  Send_Azimuth_to_USART(current_azimuth);
  led_outs[0] = 0b01000000;
  relay_outs[0] = 0b00000100;
  udn_outs[0] = current_outs_settings[6];
  HC595_Send();
}

void Set_NW() {
  current_azimuth = 315;
  Send_Azimuth_to_USART(current_azimuth);
  led_outs[0] = 0b10000000;
  relay_outs[0] = 0b00001010;
  udn_outs[0] = current_outs_settings[7];
  HC595_Send();
}

void Set_300() {
  load_outs[0] = 0b00000001;
  HC595_Send();
}

void Set_390() {
  load_outs[0] = 0b00000010;
  HC595_Send();
}

void Set_430() {
  load_outs[0] = 0b00000100;
  HC595_Send();
}

void Set_470() {
  load_outs[0] = 0b00001000;
  HC595_Send();
}

void Set_510() {
  load_outs[0] = 0b00010000;
  HC595_Send();
}

void Set_560() {
  load_outs[0] = 0b00100000;
  HC595_Send();
}

void Set_PA() {
  LL_GPIO_TogglePin(PA_ON_GPIO_Port, PA_ON_Pin);
}

void Check_PTT(void) {
  static uint32_t last_ptt_change = 0;
  uint8_t current_ptt_state = !LL_GPIO_IsInputPinSet(PTT_IN_GPIO_Port, PTT_IN_Pin);
  if ((system_tick - last_ptt_change) >= DEBOUNCE_MS) {
    if (current_ptt_state && !ptt_active) {
      pa_previous_state = LL_GPIO_IsOutputPinSet(PA_ON_GPIO_Port, PA_ON_Pin);
      LL_GPIO_ResetOutputPin(PA_ON_GPIO_Port, PA_ON_Pin);
      LL_GPIO_SetOutputPin(TX_GND_GPIO_Port, TX_GND_Pin);
      ptt_active = 1;
      last_ptt_change = system_tick;
    }
    else if (!current_ptt_state && ptt_active) {
      if (pa_previous_state) {
        LL_GPIO_SetOutputPin(PA_ON_GPIO_Port, PA_ON_Pin);
      } else {
        LL_GPIO_ResetOutputPin(PA_ON_GPIO_Port, PA_ON_Pin);
      }
      LL_GPIO_ResetOutputPin(TX_GND_GPIO_Port, TX_GND_Pin);
      ptt_active = 0;
      last_ptt_change = system_tick;
    }
  }
}


/* USER CODE END 0 */

/**
  * @brief  The application entry point.
  * @retval int
  */
int main(void)
{

  /* MCU Configuration--------------------------------------------------------*/

  /* Reset of all peripherals, Initializes the Flash interface and the Systick. */
  HAL_Init();

  /* Configure the system clock */
  SystemClock_Config();

  /* Initialize all configured peripherals */
  MX_GPIO_Init();
  MX_SPI1_Init();
  MX_USART1_UART_Init();
  MX_TIM17_Init();
  /* USER CODE BEGIN 2 */
  LL_USART_Enable(USART2);
  LL_USART_EnableIT_RXNE(USART1);
  Init_Buttons();
  relay_outs[0] = 0;
  load_outs[0] = 0;
  udn_outs[0] = 0;
  led_outs[0] = 0;
  HC595_Send();
  Say_Hi();
  Load_Button_Settings(current_outs_settings);
  if (current_outs_settings[0] == 0xFF) {
    Save_Button_Settings(button_settings);
    Load_Button_Settings(current_outs_settings);
  }

  /* USER CODE END 2 */

  /* Infinite loopc */
  /* USER CODE BEGIN WHILE */
  while (1)
  {
    Check_Usart_Data();
    Buttons_Poll();
    Check_Buttons();
    Check_PTT();
    /* USER CODE END WHILE */

    /* USER CODE BEGIN 3 */
  }
  /* USER CODE END 3 */
}

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


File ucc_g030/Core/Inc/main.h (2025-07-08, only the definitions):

#define BTN_470_Pin LL_GPIO_PIN_9
#define BTN_470_GPIO_Port GPIOB
#define BTN_390_Pin LL_GPIO_PIN_14
#define BTN_390_GPIO_Port GPIOC
#define BTN_430_Pin LL_GPIO_PIN_15
#define BTN_430_GPIO_Port GPIOC
#define OE_Pin LL_GPIO_PIN_0
#define OE_GPIO_Port GPIOA
#define RCLK_Pin LL_GPIO_PIN_3
#define RCLK_GPIO_Port GPIOA
#define BUZZER_Pin LL_GPIO_PIN_4
#define BUZZER_GPIO_Port GPIOA
#define BTN_510_Pin LL_GPIO_PIN_5
#define BTN_510_GPIO_Port GPIOA
#define BTN_560_Pin LL_GPIO_PIN_6
#define BTN_560_GPIO_Port GPIOA
#define PTT_IN_Pin LL_GPIO_PIN_7
#define PTT_IN_GPIO_Port GPIOA
#define BTN_N_Pin LL_GPIO_PIN_0
#define BTN_N_GPIO_Port GPIOB
#define BTN_NE_Pin LL_GPIO_PIN_1
#define BTN_NE_GPIO_Port GPIOB
#define BTN_E_Pin LL_GPIO_PIN_2
#define BTN_E_GPIO_Port GPIOB
#define TX_GND_Pin LL_GPIO_PIN_8
#define TX_GND_GPIO_Port GPIOA
#define BTN_300_Pin LL_GPIO_PIN_6
#define BTN_300_GPIO_Port GPIOC
#define PA_ON_Pin LL_GPIO_PIN_15
#define PA_ON_GPIO_Port GPIOA
#define BTN_SE_Pin LL_GPIO_PIN_3
#define BTN_SE_GPIO_Port GPIOB
#define BTN_S_Pin LL_GPIO_PIN_4
#define BTN_S_GPIO_Port GPIOB
#define BTN_SW_Pin LL_GPIO_PIN_5
#define BTN_SW_GPIO_Port GPIOB
#define BTN_W_Pin LL_GPIO_PIN_6
#define BTN_W_GPIO_Port GPIOB
#define BTN_NW_Pin LL_GPIO_PIN_7
#define BTN_NW_GPIO_Port GPIOB
#define BTN_PA_Pin LL_GPIO_PIN_8
#define BTN_PA_GPIO_Port GPIOB

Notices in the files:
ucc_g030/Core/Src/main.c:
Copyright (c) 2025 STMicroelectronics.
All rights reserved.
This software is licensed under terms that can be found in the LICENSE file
